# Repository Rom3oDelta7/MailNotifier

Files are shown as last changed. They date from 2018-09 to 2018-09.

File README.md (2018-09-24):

# MailNotifier
Hardware and software solution to be notified when your mail arrives

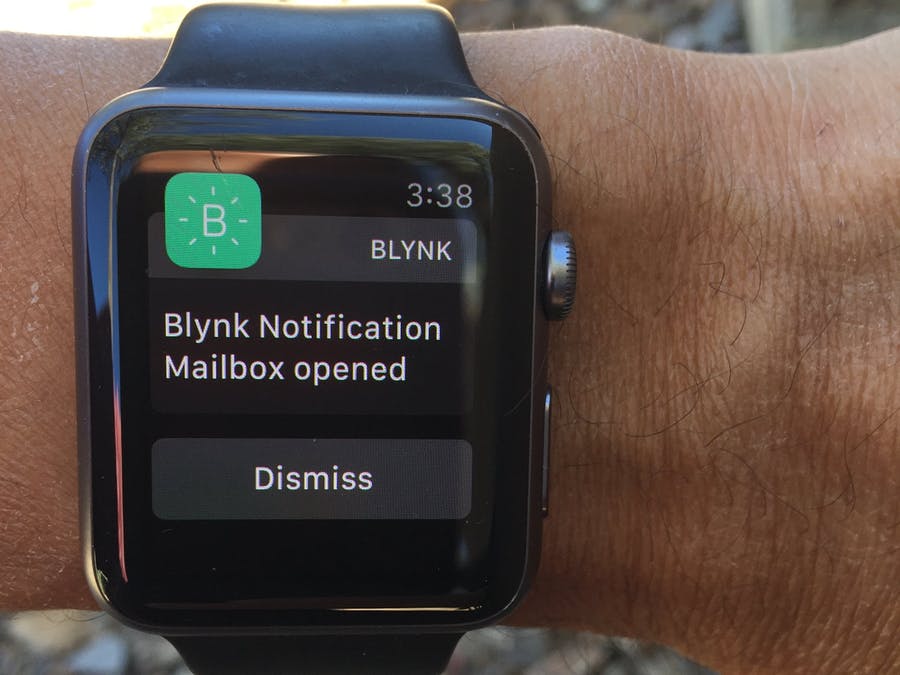
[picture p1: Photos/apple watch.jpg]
Apple Watch notification


This is a simple system that will notify you when your mailbox has been delivered.
You get a notification for the first opening (mail delivered) and the second (mail collected).
These notifications will be sent to your phone using both Blynk and SMS text.
If you have an Apple Watch, the notification will be displayed on the watch as well (see picture above).
The Blynk dashboard provides more information and options, including the date and time the mail was delivered,
what the operating hours are, and status LEDs.

Since the wiring was already in place for my home
I designed this with a wired connection to my mailbox using a standard magnetic reed switch such as that found in
security systems.
Any normally closed switch can be used to sense when the mailbox is open.
If your installation requires a normally open switch instead,
there is a single define in the code that allows you to change the sense.

See more about this projects on [hackster.io].

## Hardware

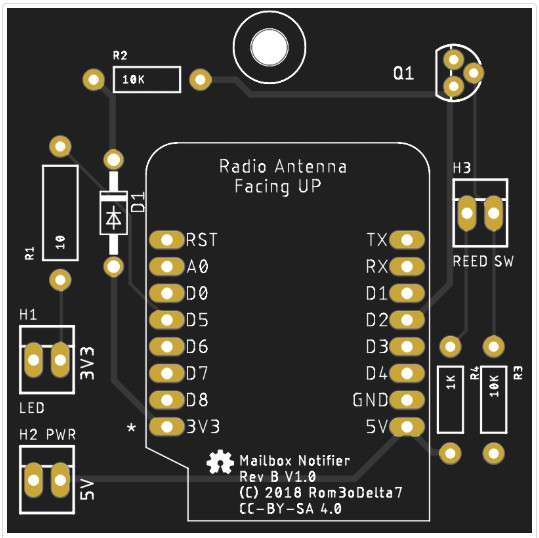
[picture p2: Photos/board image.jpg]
board image


The hardware is quite simple. 
A WeMOS D1 R2 Mini (ESP8266) is used as the controller. There are just 3 connections:
1. the reed switch (which should be normally closed (e.g. magnet is engaged)), and
1. a status LED
1. 5V DV power

The system requires a 5V 1A DC power supply.

Earlier versions of this system suffered from EMI (electromagnetic interference) when lightning stuck nearby
(a common occurrence during the summer monsoons) due in part to a long wire out to the mailbox acting as an antenna.
In Rev B hardware (and Rev 2 software), this issue is handled sensing the switch differently to distinguish an open event from EMI.
Moreover, the lightning-caused high-voltage EMI over time caused the input port to go deaf requiring replacement of the MCU.
Rev B hardware insulates the ESP8266 input port from the external line with a diode and a MOSFET;
these parts have much higher voltage tolerances are easier and cheaper to replace than the ESP8266 MCU module.

PCBs may be ordered from PCBs.io at https://PCBs.io/share/49aNb.

## User Interface

The user interface is shown below:

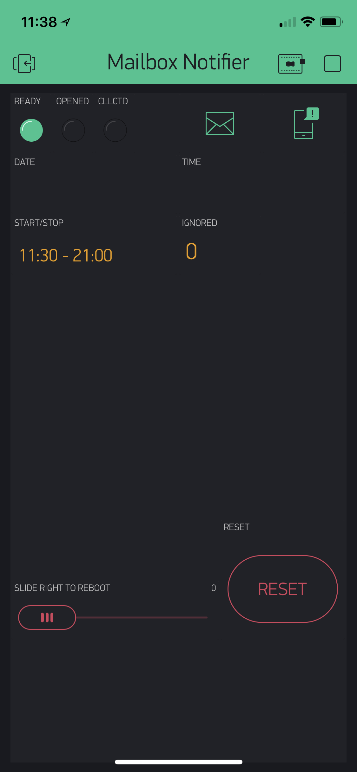
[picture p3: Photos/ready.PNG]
ready state


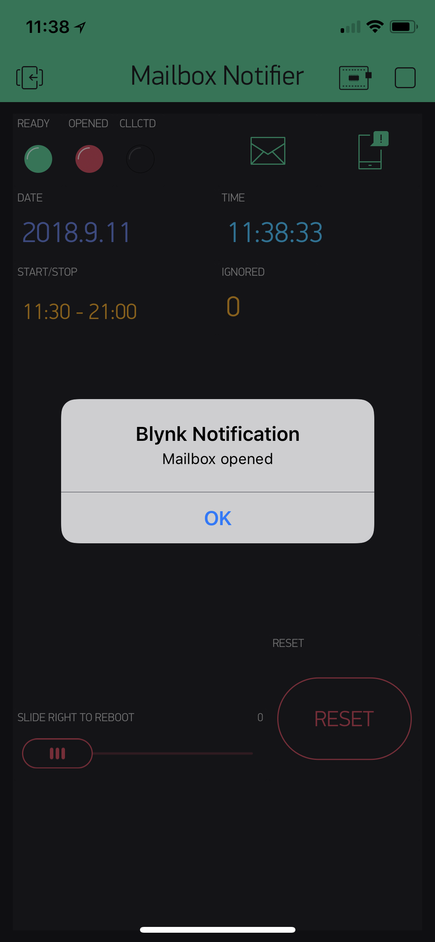
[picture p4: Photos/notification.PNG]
open notification


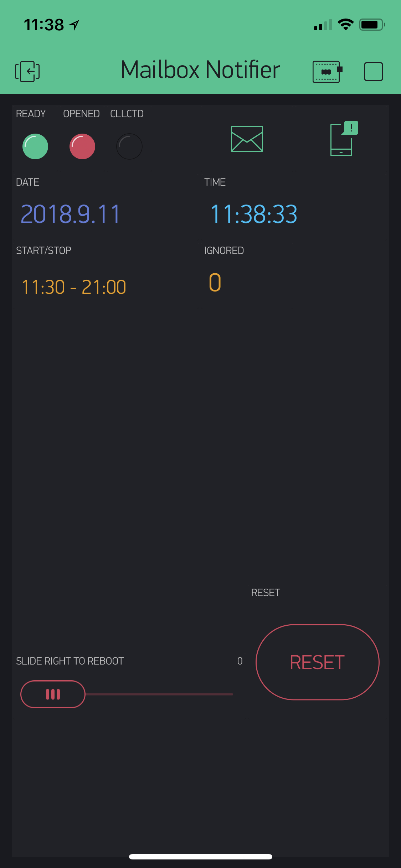
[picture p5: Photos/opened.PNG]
after mail delivered


* The "READY" LED (green) indicates that the mailbox is currently closed.
Note that the ready light will not be on outside operating hours (see below).
* The "OPENED" LED (red) indicates that the mailbox has been opened.
* The "CLLCTD" LED (blue) indicates that the mail has been collected.
This is a heuristic: it is activated if the mailbox is opened _again_ after 10 minutes.
* "DATE" and "TIME" indicate the date (YYYY.MM.DD) and time (24 hr) the mailbox was first opened.
If the mailbox is opened multiple times, the date & time do _not_ change;
you must reset the system (see below) to clear the date & time and reset the indicators.
* The "STOP/START" field is used to set operating hours.
The default is 1100 to 2000 hours.
* "IGNORED" indicates how many times the mailbox was opened outside operating hours.
* The "RESET" button resets the LEDs and the date & time displays.
Note that the system will reset itself automatically at midnight each day.
* The "REBOOT" slider is used to reboot the system.
To reboot, slide the switch all the way to the right.
You have 5 seconds to change your mind and slide it back to the left.
The "READY" LED will extinguish, a message about canceling the reboot will appear in the DATE and TIME displays,
and the system will reboot after a 5 second delay.
Note that this mechanism can also be used to ensure the end-to-end system is running: if the reboot message comes up
this indicates the system is active - just quickly slide the switch back to the left.

Note that all of the built-in delays and timing heuristics can be easily personalized by changing the C++ preprocessor defines in the sketch.

## Firmware

The C++ code uses the [Blynk] service. 
You must first download the Blynk app for your smartphone (iOS or Android) and sign up for the service.
You can then download this app from within Blynk using the QR code in the "Blynk" folder.

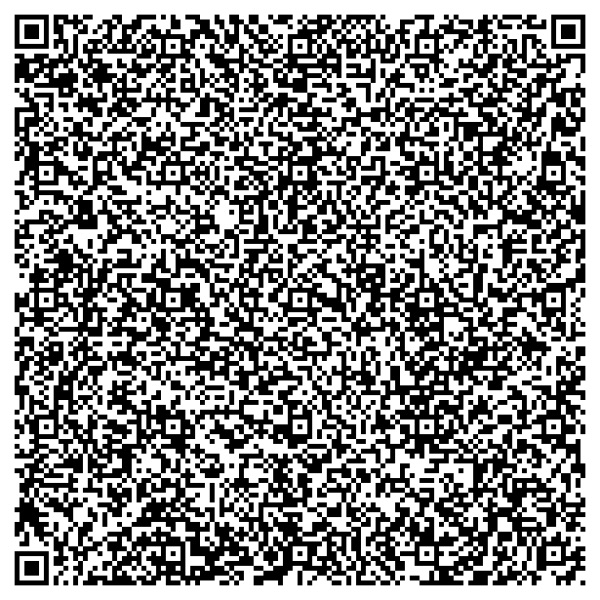
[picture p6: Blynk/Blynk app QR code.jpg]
Blynk mail notifier app QR code


See the [Blynk getting started guide].

The code uses the [Blynk Library], my [NTP (Network Time Protocol) clock library], and Paul Stoffregen's [Time Library].
Be sure to change the "auth", "SSID", and "password" strings
and set the email address string to the [address your carrier uses to send an SMS to your phone] in the file "locals.h". 
In the sketch file, set the parameter to the

```C++
NTP_UTC_Timezone()
```

function to your local timezone. 
See ```WorldTimezones.h``` in the [NTP (Network Time Protocol) clock library] for details and
a list of timezones you can set.

The code may be updated using OTA (Over The Air) updates.
You can still upload the code in the traditional USB approach, but after the firmware has been uploaded for the first time
you can upload subsequent updates over WiFi. 
See the [ESP8266 OTA update documentation] for details.

__Important__: access to the current time is fundamental to the operation of the system.
Therefore, you must have Internet access for the NTP library to work. 

## Enclosure

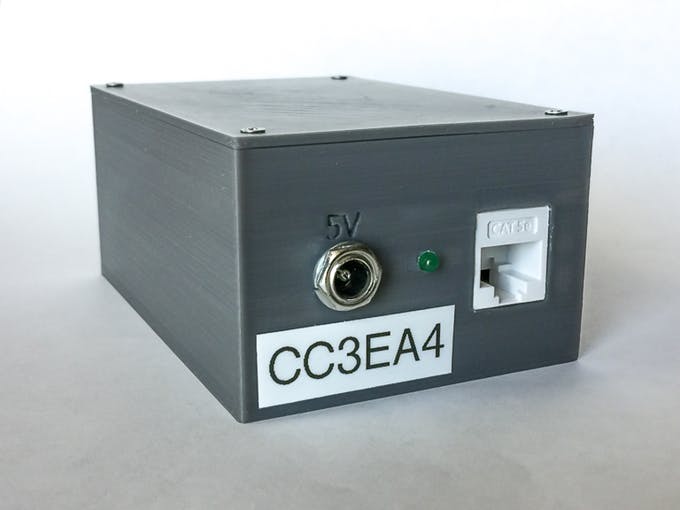
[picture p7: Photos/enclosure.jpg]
enclosure


The STL files to 3D print the enclosure are included in the repo:
one file for the base and one for the lid.
The wiring I piggybacked onto to reach my mailbox happens to come into a patch panel,
so I have an RJ45 jack opening in my enclosure, which is what you see in the picture. 
In your slicing software you should turn on support for the RJ45 opening.
Just about any filament is fine - I used PLA with a layer height of 0.4mm. 
The HEX address you see on the label is the unit address fro OTA updates.

## Implementation

### Assembly

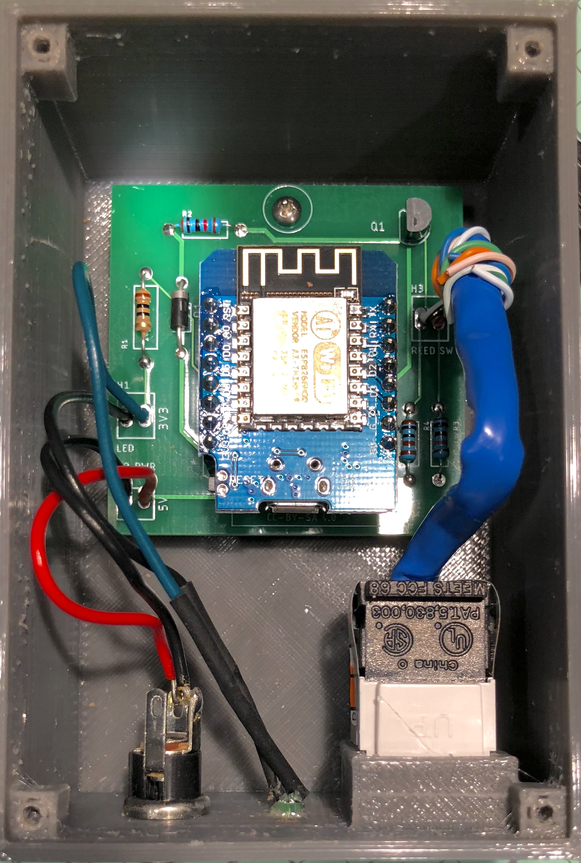
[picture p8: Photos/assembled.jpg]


* 3D print the enclosure base and lid.
* Assemble the discrete components to the PCB.
* Solder the female headers that come with the WeMOS to the PCB.
* If using the RJ45 connector, punch down the switch connection wires into the RJ45 keystone connector,
leaving enough wire to comfortably reach the PCB.
Then insert the RJ45 into the case.
* Solder the connection for the LED and use some 2mm shrink wrap tubing to protect the leads from shorting
(or electrical tape if you don't have this).
* Mount the LED.
The hole is sized for a 3mm LED. If the fit is too loose, then secure the LED to the case with some
UV-curable resin (preferred) or hot melt glue.
If you don't use a green LED, you should recalculate the value of the current limiting resistor
to match the Vf of your LED.
If you don't know what this means, just use a green LED.
* Solder the power wires to the DC power jack and fasten to the case.
* Solder the wires to the PCB: power, switch, and LED, being sure to observe the correct polarity (marked on the PCB).
* Insert the WeMOS into the headers.
__Note:__ You can mount the PCB to the enclosure now, but you will probably find it easier to program it first
(see below).
* Fasten the board to the mounting post in the base of the enclosure.
* Attach the lid using the flat head screws.

### Programming

* Ensure the aforementioned local/personal changes have been implemented in the sketch (.ino) file and "locals.h".
* For the first upload, connect a microUSB plug to the WeMOS.
* In the Arduino IDE, select the "LOLIN(WeMos)D1 R2 & Mini" board.
* Board settings:

|Parameter|Setting|
|---|---|
|CPU Frequency|160 MHz|
|Flash Size|4M(1M SPIFFS)|
|Upload SPeed|921600|
|Port|_your USB serial port_|

* The WeMOS has an automatic system for enabling the flash sequence so no buttons need to be pressed.
* After the code is uploaded, the green LED will illuminate when all of the setup and initialization steps are complete.
* While the serial cable is still connected, open the serial port (115200 baud) and reset the WeMOS.
The HEX address you need to do OTA updates will be printed.
Save this for future use.
At this point, you can launch the Blynk app and run the notifier app dashboard. 
* The USB cable may now be removed.

# Copyright

Copyright 2018 Rob Redford.
This work is licensed under the Creative Commons Attribution-ShareAlike 4.0 International License.
To view a copy of this license, visit [CC-BY-SA].

[hackster.io] https://www.hackster.io/Rom3oDelta7/smartphone-mailbox-notifier-version-2-sept-2018-822a1d
[Blynk]: http://www.blynk.cc/
[Blynk Library]: http://www.blynk.cc/getting-started/
[Blynk getting started guide]: http://www.blynk.cc/getting-started/
[NTP (Network Time Protocol) clock library]: https://github.com/Rom3oDelta7/NTP-RTC
[Time Library]: http://www.pjrc.com/teensy/td_libs_Time.html
[ESP8266 OTA update documentation]: https://arduino-esp8266.readthedocs.io/en/latest/ota_updates/readme.html
[address your carrier uses to send an SMS to your phone]: http://www.digitaltrends.com/mobile/how-to-send-e-mail-to-sms-text/
[CC-BY-SA]: https://creativecommons.org/licenses/by-sa/4.0/

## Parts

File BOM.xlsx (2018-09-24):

Item | Qty | Description | Purchase URL (examplse - available at multiple outlets)
WebMOS D1 mini V2 | 1 | ESP8266-based microcontroller | https://www.banggood.com/WeMos-D1-mini-V2_2_0-WIFI-Internet-Development-Board-Based-ESP8266-4MB-FLASH-ESP-12S-Chip-p-1143874.html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
PCB | 1 | printed circuit board | https://pcbs.io/share/49aNb
Blynk App | 1 | Blynk app & runtime library | www.blynk.cc
1K 1/4W resistor | 1 | 1K PTH resistor | https://octopart.com/search?q=resistor%201K%20ohm%201%2F4%20watt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
10K 1/4W resistor | 2 | 10K PTH resistor | https://octopart.com/search?q=resistor%2010K%20ohm%201%2F4%20watt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
10 ohm 1/4W resistor | 1 | 10 ohm PTH resistor | https://octopart.com/search?q=resistor%2010%20ohm%201%2F4%20watt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
DC jack | 1 | DC power input jack (5.5, 2.1) | https://smile.amazon.com/uxcell-5-5mmx2-1mm-Socket-Mounting-Connector/dp/B01ERPCV1Y
945T magnetic contact | 1 | magnetic reed switch | https://smile.amazon.com/Ademco-945T-WH-Miniature-Surface-Terminals/dp/B000GUQKGC
#2 3/8" flat head screw | 4 | lid screws
#2 1/4" sheet metal screw | 1 | PCB fastener
Green LED | 1 | T-1 (3mm) PTH green LED | https://octopart.com/tlhg4400-vishay-39404959?r=sp&s=afxfcSvbQpS9Ntd6rMgB_Q
MOSFET | 1 | 2N7000 TO-92 pkg | https://octopart.com/search?r=sp&s=afxfcSvbQpS9Ntd6rMgB_Q&q=2N7000&start=0
Diode | 1 | 1N4007 | https://octopart.com/1n4007-t-diodes+inc.-55389582?r=sp&s=AmIHlQKgSlimIGmMg_WMyg
RJ-45 jack | 1 | RJ-45 Cat5e keystone | https://www.monoprice.com/product?p_id=5376
3D printing filament
22 AWG hookup wire

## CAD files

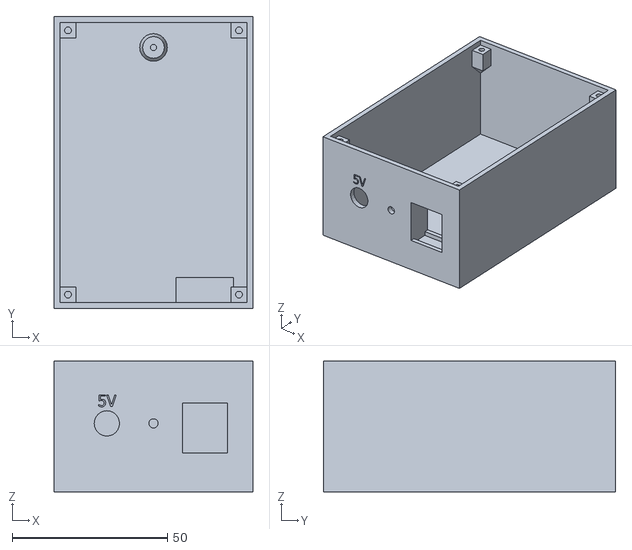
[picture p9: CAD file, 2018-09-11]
Enclosure/Mailbox Notifier Enclosure 0.4.stl
64.0 x 94.0 x 42.0

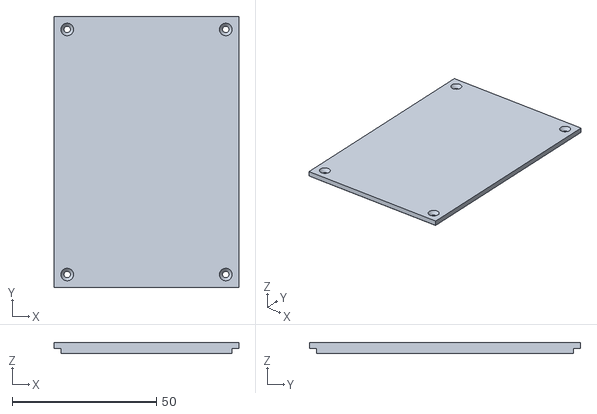
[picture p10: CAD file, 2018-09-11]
Enclosure/Mailbox Notifier Enclosure Lid 0.4.stl
64.0 x 94.0 x 3.80

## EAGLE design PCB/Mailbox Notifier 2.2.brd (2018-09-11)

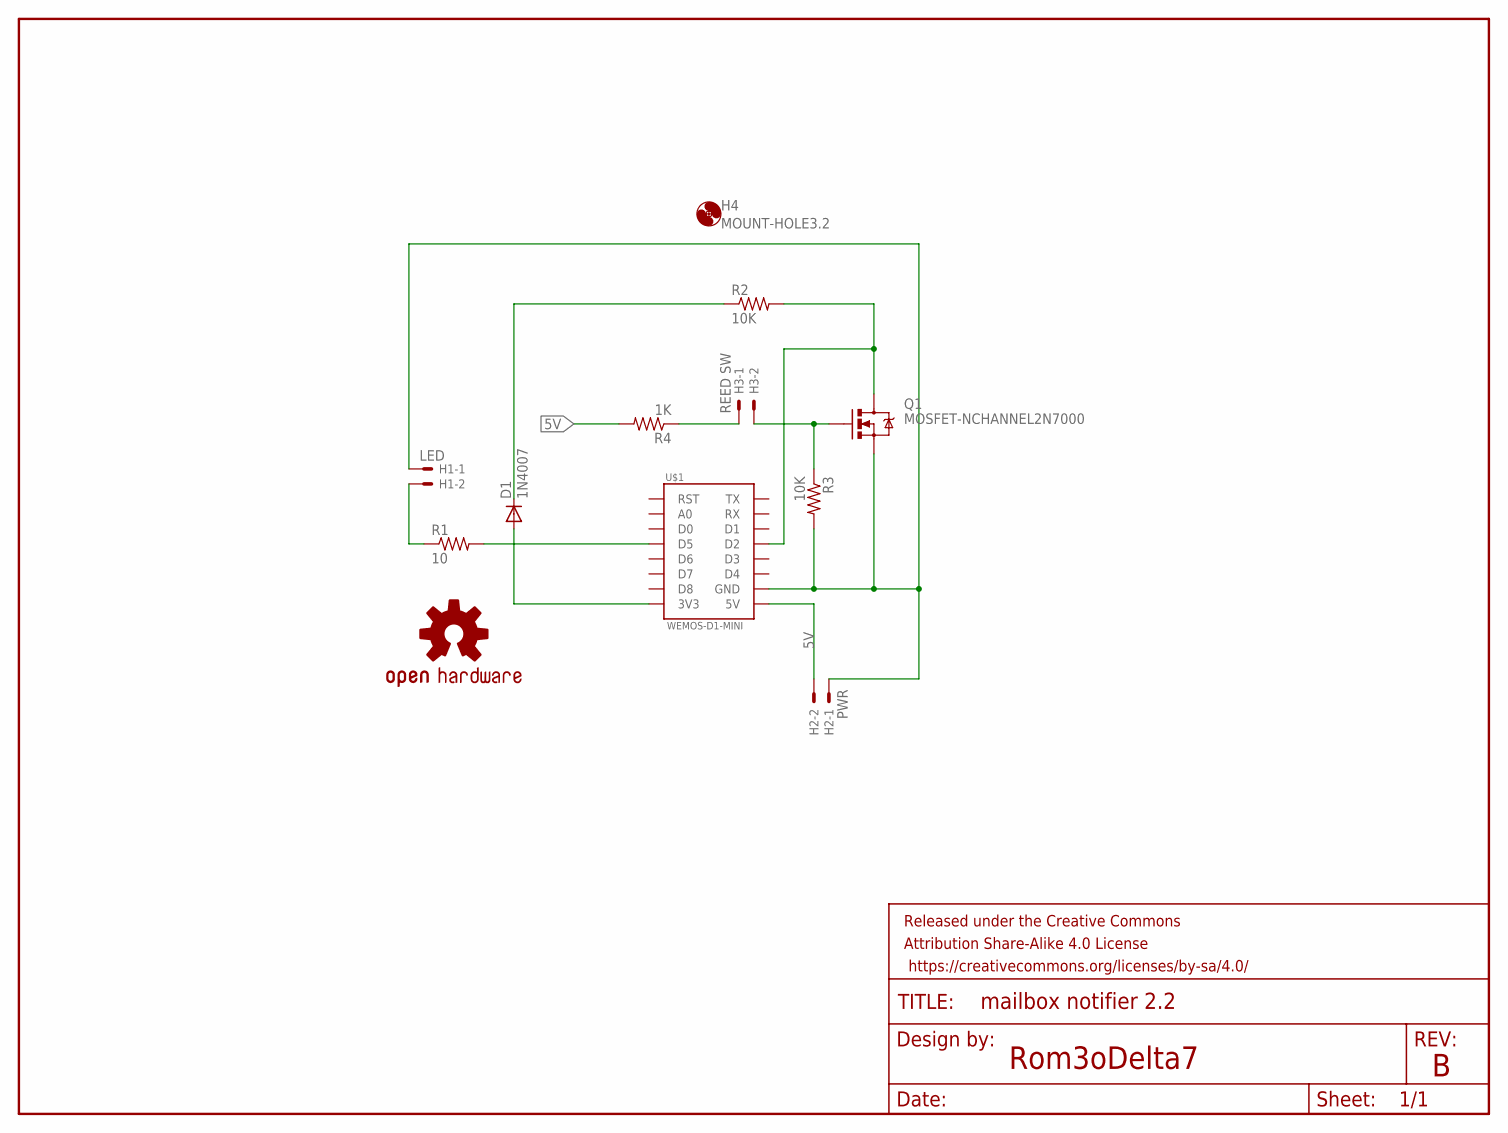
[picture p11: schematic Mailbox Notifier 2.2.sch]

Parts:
D1: 1N4007; DO41-10
FRAME1: FRAME-LETTER; CREATIVE_COMMONS
H1: LED; 22-23-2021
H2: PWR; 22-23-2021
H3: REED SW; 22-23-2021
H4: MOUNT-HOLE3.2; 3,2
LOGO1: OSHW-LOGOMINI; OSHW-LOGO-MINI
Q1: MOSFET-NCHANNEL2N7000; TO-92
R1: 10; AXIAL-0.5
R2, R3: 10K; AXIAL-0.4
R4: 1K; AXIAL-0.4
U$1: WEMOS-D1-MINI

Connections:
5V: H2.2, R4.P$2 (2), U$1.5V
GND: H1.1, H2.1, Q1.1 (S), R3.P$2 (2), U$1.GND
unnamed: D1.A, U$1.3V3
unnamed: H3.2, Q1.2 (G), R3.P$1 (1)
unnamed: R1.P$2 (2), U$1.D5
unnamed: H1.2, R1.P$1 (1)
unnamed: Q1.3 (D), R2.P$2 (2), U$1.D2
unnamed: D1.C, R2.P$1 (1)
unnamed: H3.1, R4.P$1 (1)

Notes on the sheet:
Rom3oDelta7

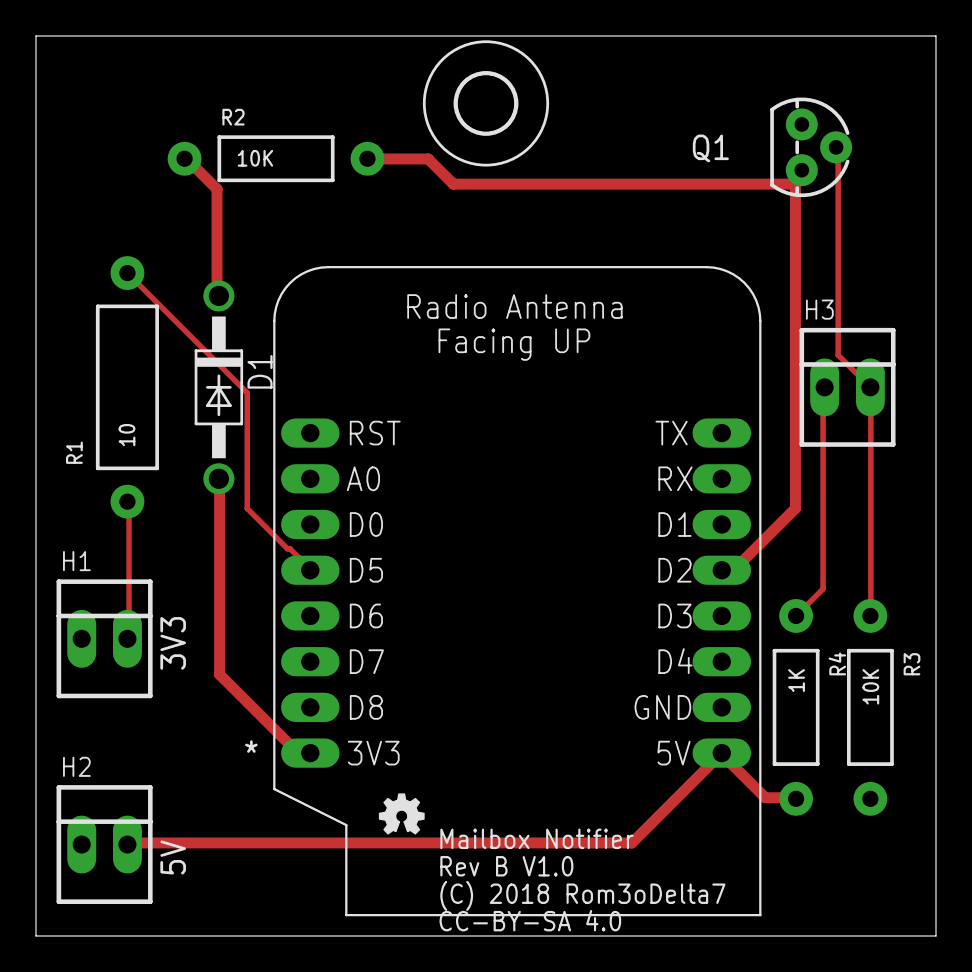
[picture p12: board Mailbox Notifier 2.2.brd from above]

Board: 2 copper layers, 50.0 x 50.0 mm, 13 parts (0 on the bottom side), 9 nets.

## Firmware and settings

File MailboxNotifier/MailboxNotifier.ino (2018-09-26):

/*
	TABS=3
	Mailbox notifier
	Simple Blynk interface for a  magnetic reed switch application
	Supports OTA uploads

	Copyright 2017/2018 Rob Redford
	This work is licensed under the Creative Commons Attribution-ShareAlike 4.0 International License (CC-BY-SA).
	To view a copy of this license, visit https://creativecommons.org/licenses/by-sa/4.0/

*/

//#define DEBUG 3                                    // define as MAX desired debug level, or comment out to disable debug statements

#ifdef DEBUG
   #define BLYNK_PRINT Serial
   #define DEBUG_MSG(L, H, M)	       if ((L) <= DEBUG) {Serial.print("DEBUG> "); Serial.print(H); Serial.print(": "); Serial.println(M);}
#else
   #define DEBUG_MSG(...)            ;
#endif

#include <ESP8266WiFi.h>
#include <BlynkSimpleEsp8266.h>
#include <TimeLib.h>
#include <WiFiUdp.h>
#include <ArduinoOTA.h>
#include <NTPRTC.h>											// https://github.com/Rom3oDelta7/NTP-RTC
#include <WorldTimezones.h>								// https://github.com/Rom3oDelta7/NTP-RTC

// ============================= Local Settings ==================================================

#include "locals.h"

// ============================= Blynk ==================================================

#define DATE_DISPLAY		V1									// Labeled Value, L
#define TIME_DISPLAY		V2									// Labeled Value, L
#define LED_READY			V3									// LED
#define LED_OPEN			V4									// LED
#define RESET_BUTTON		V5									// Button, PUSH
#define START_STOP	   V6									// Time input
#define LED_COLLECTED	V7									// LED
#define REBOOT_SLIDER	V8									// Slider, small
#define IGNORED_EVENTS  V9                         // Value, Small

WidgetLED readyLED(LED_READY);
WidgetLED openedLED(LED_OPEN);
WidgetLED collectedLED(LED_COLLECTED);

// ============================= Hardware & Logic ==========================================

#define NOISE_WINDOW       250                     // dwell time in msec for switch bounce & EMI noise
#define COLLECTION_DELAY	600							// delay in sec after opening before collection window opens
#define CHECK_INTERVAL     500                     // how frequently to check the mailbox (msec)
#define REBOOT_DELAY			5000							// delay in msec for reboot slider

#define DEFAULT_START  		(11 * 3600)	            // 11AM - for operating window
#define DEFAULT_STOP			(20 * 3600)             // 8PM

int      startTimeInSecs = DEFAULT_START;	         // start & stop times from dashboard settings
int      stopTimeInSecs = DEFAULT_STOP;     

int      ignoredEventCount = 0;                    // count of opening events that were ignored

enum CollectionState { C_INACTIVE, C_PENDING, C_ACTIVE };
CollectionState waitingForCollection;				   // flag for 2nd opening, which we assume is to collect the mail

bool     cycleComplete = false;                    // set after mail has been collected to disable further notifications for the day

// use "LOLIN(WeMos)D1 R2 & Mini" to get these defines D2=2, D5=14
#define SWITCH_PIN		D2									// NC switch connected to ground
#define RUNNING_LED		D5									// LED pilot light; 10 ohm resistor, Green LED

#define SENSE_CLOSED    LOW                        // send pin state when mailbox is closed: open:high, closed:low
  

/*
 reset the mailbox switch to normal state
*/
void resetMbox ( void ) {
	openedLED.off();
	collectedLED.off();
	ignoredEventCount = 0;
	Blynk.virtualWrite(TIME_DISPLAY, " ");
	Blynk.virtualWrite(DATE_DISPLAY, " ");
	Blynk.virtualWrite(IGNORED_EVENTS, ignoredEventCount);
	waitingForCollection = C_INACTIVE;
   cycleComplete = false;
}

/*
 Blynk dashboard reset button
*/
BLYNK_WRITE ( RESET_BUTTON ) {
	resetMbox();
}

/*
 set the start and stop time for monitoring the mailbox
 use the Blynk convention of seconds since midnight
 if user does not set this the sketch assumes 24 hour operation
*/
BLYNK_WRITE ( START_STOP ) {
	TimeInputParam startStopTime(param);

	DEBUG_MSG(0, "Called", "START_STOP <<<<<<<<<<<<<<<<<<<<<<<<<<<<<<<<<<<<");
	if ( startStopTime.hasStartTime() ) {
		startTimeInSecs = param[0].asInt();
		if ( startTimeInSecs == -1 ) {
			// no user data entered
			startTimeInSecs = 0;
		}
		DEBUG_MSG(1, "\t\tStart", startTimeInSecs);
	}
	if ( startStopTime.hasStopTime() ) {
		stopTimeInSecs = param[1].asInt();
		if ( stopTimeInSecs == -1 ) {
			stopTimeInSecs = (23*3600) + (59*60) + 59;            // one sec before midnight
		}
		DEBUG_MSG(1, "\t\tStop", stopTimeInSecs);
	}
}


/*
 Reboot the ESP when the slider is all the way to the right (with some margin) but allow the user
 to slide it back to cancel within the specified delay (see above)
 
 Note this can also be used as a test to verify that the ESP is online and responding to commands
*/
BLYNK_WRITE ( REBOOT_SLIDER ) {
	int 		value = param.asInt();
	static 	bool rebootInitiated = false;
	static 	uint32_t rebootRequested = 0;
	
	if ( !rebootInitiated ) {
		if ( value > 90 ) {
			// slider is set to send 0:100
			Blynk.virtualWrite(DATE_DISPLAY, "Slide to 0");
			Blynk.virtualWrite(TIME_DISPLAY, "to cancel");
			rebootInitiated = true;
			rebootRequested = millis();
			readyLED.off();													// turn off to indicate a pending reboot
			Blynk.syncVirtual(REBOOT_SLIDER);                     // send new widget values to dashboard	by forcing call to BLYNK_WRITE()
		}
	} else {
		// process reboot request
		if ( value <= 10 ) {
			// cancel reboot
			rebootInitiated = false;
			Blynk.virtualWrite(DATE_DISPLAY, " ");
			Blynk.virtualWrite(TIME_DISPLAY, " ");
			if ( digitalRead(SWITCH_PIN) == SENSE_CLOSED ) {
				readyLED.on();
			}
		} else if ( (millis() - rebootRequested) < REBOOT_DELAY ) {
			// don't want to call delay(), so just request the value again from the server
			Blynk.syncVirtual(REBOOT_SLIDER);
		} else {
			// still set after delay, so reboot now
			ESP.restart();
			delay(1000);
		}
	}
}

/*
 SETUP
*/
void setup ( void ) {
	Serial.begin(115200);									// always instantiate Serial for OTA messages
   delay(20);
	DEBUG_MSG(0, "Mbox", "*** STARTUP***");

	pinMode(SWITCH_PIN, INPUT);					      // normally closed switch
	pinMode(RUNNING_LED, OUTPUT);
	digitalWrite(RUNNING_LED, LOW);
	
	Blynk.begin(auth, ssid, pass);
	while ( !Blynk.connect() ) {							// wait for connection
		Blynk.run();
	}
	DEBUG_MSG(0, "Mbox", "Blynk CONNECTED");

	if ( digitalRead(SWITCH_PIN) == SENSE_CLOSED ) {
		readyLED.on();
	} else {
		readyLED.off();
	}

	openedLED.off();
	collectedLED.off();
   cycleComplete = false;
   waitingForCollection = C_INACTIVE;
   ignoredEventCount = 0;
	Blynk.virtualWrite(TIME_DISPLAY, " ");
	Blynk.virtualWrite(DATE_DISPLAY, " ");
	Blynk.virtualWrite(IGNORED_EVENTS, ignoredEventCount);
	// the following do not currently work	:-(
	//Blynk.setProperty(START_STOP, "color", "#ED9D00");     // change color to yellow
	//Blynk.virtualWrite(START_STOP, DEFAULT_START, DEFAULT_STOP);
	Blynk.syncVirtual(START_STOP);                           // get current start/stop times

	// initialize NTP source for RTC data
	NTP_UTC_Timezone(UTC_MST);
	NTP_Init();
	
	/*
	 OTA setup
	*/
	// Port defaults to 8266
	ArduinoOTA.setPort(8266);

	// Hostname defaults to esp8266-[ChipID]
	//ArduinoOTA.setHostname("myesp8266");

	// No authentication by default
	//ArduinoOTA.setPassword((const char *)"@kermit87");

	ArduinoOTA.onStart([]() {
		Serial.println("Start");
	});
	ArduinoOTA.onEnd([]() {
		Serial.println("\nEnd. Restarting ...");
		ESP.restart();
		delay(1000);
	});
	ArduinoOTA.onProgress([](unsigned int progress, unsigned int total) {
		Serial.printf("Progress: %u%%\r", (progress / (total / 100)));
	});
	ArduinoOTA.onError([](ota_error_t error) {
		Serial.printf("Error[%u]: ", error);
		switch ( error ) {
		case OTA_AUTH_ERROR:
			Serial.println("Auth Failed");
			break;
			
		case OTA_BEGIN_ERROR:
			Serial.println("Begin Failed");
			break;
			
		case OTA_CONNECT_ERROR:
			Serial.println("Connect Failed");
			break;
			
		case OTA_RECEIVE_ERROR:
			Serial.println("Receive Failed");
			break;
			
		case OTA_END_ERROR:
			Serial.println("End Failed");
			break;
			
		default:
			Serial.println("Unknown error");
			break;
		}
	});
	ArduinoOTA.begin();
	Serial.println("OTA Ready:");
	Serial.print("\tIP address: ");
	Serial.println(WiFi.localIP());
	Serial.print("\tChip ID: ");
	Serial.println(ESP.getChipId(), HEX);
	
	digitalWrite(RUNNING_LED, HIGH);
}

/*
 update Blynk dashboard with the time the mailbox was opened
*/
void displayOpenedTime ( void ) {
	char    currentTime[9];
	time_t  timeNow = now();
	
	// use a constant time value to avoid corner cases where, for example, the hour changes between function calls
	sprintf(currentTime, "%02d:%02d:%02d", hour(timeNow), minute(timeNow), second(timeNow));
	String currentDate = String(year(timeNow)) + "." + month(timeNow) + "." + day(timeNow);
	DEBUG_MSG(2, "current time", currentTime);
	DEBUG_MSG(2, "current date", currentDate);

	Blynk.virtualWrite(TIME_DISPLAY, currentTime);
	Blynk.virtualWrite(DATE_DISPLAY, currentDate);
}

/*
 Check switch pin to determine if the mailbox is open.
 
 When the switch is closed, the MOSFET gate will be high and the MOSFET will be "on", connecting the 
 drain and source and grounding the connection. In this state the 8266 pin will read "low".
 When the switch is open, the gate will be pulled low, and the MOSFT will be off. The 8266 pin will then read the voltage differential 
 on the drain pin and  read as "high".
 
 But if this is an EMI event instead, then after some initial noise, the line will still be low.
 Therefore, if the pin is high, wait for the debounce/EMI noise to settle, then read the line again -
 this should be the actual state.
 
 Note: the EMI issue only comes into play if we happen to be reading the pin while the EMI is occurring.
 Since we're reading the pin quite frequently, this may still happen. Adjust the delay if the time interval is insufficient,
 but don't wait so long that the mailbox may have been closed after delivery (and thus missing the event).
 */
bool mailboxIsOpen ( void ) {
   if ( digitalRead(SWITCH_PIN) == SENSE_CLOSED ) {
      return false;
   } else {
      // if low again after delay, then initial read was a false positive
      delay(NOISE_WINDOW);
      return digitalRead(SWITCH_PIN);
   }
}

/*
 LOOP
*/
void loop ( void ) {
	static int    today = day();
	static time_t timeOpened = 0;
   static bool    ignoredEventCounted = false;
#ifdef DEBUG
	static bool   displayed = false;
#endif
	
	if ( today != day() ) {
		// automatically reset state every day
		today = day();
		resetMbox();
	}
	
	// check for operating hours. Default (params not set by user) is 24hr operation
	int currentTimeinSecs = ((3600 * hour()) + (60 * minute()) + second());
#if DEBUG > 3
	if ( (second() % 5) == 0 ) {
		if ( !displayed ) {
			displayed = true;
			DEBUG_MSG(3, "current seconds since midnight", currentTimeinSecs);
			DEBUG_MSG(3, "start", startTimeInSecs);
			DEBUG_MSG(3, "stop", stopTimeInSecs);
		}
	} else {
		displayed = false;
	}
#endif
   
   delay(CHECK_INTERVAL);                   // no need to constantly check - also helps with EMI
   if ( !cycleComplete ) {
      bool mailboxOpen = mailboxIsOpen();
      DEBUG_MSG(2, "Loop:Status:", mailboxOpen);
      if ( (currentTimeinSecs >= startTimeInSecs) && (currentTimeinSecs < stopTimeInSecs) ) {
         // inside the operating window
         if ( mailboxOpen ) {
            // mailbox initial open
            DEBUG_MSG(2, "OPEN: Collection state:", waitingForCollection);
            readyLED.off();

            switch ( waitingForCollection ) {
               case C_INACTIVE:
                  // first time mailbox has been opened
                  DEBUG_MSG(2, "Loop:\t", "mailbox opened");
                  Blynk.email(SMS_EMAIL, "Mbox Notifier", "Mailbox opened");
                  Blynk.notify("Mailbox opened");
                  displayOpenedTime();
                  timeOpened = now();
                  openedLED.on();
                  waitingForCollection = C_PENDING;
                  ignoredEventCounted = false;
                  break;
                  
               case C_ACTIVE:
                  if ( (now() - timeOpened) >= COLLECTION_DELAY ) {
                     /*
                      second opening - assume this is to collect the mail
                      ignore it if not enough time has passed yet 
                     */
                     collectedLED.on();
                     Blynk.email(SMS_EMAIL, "Mbox Notifier", "Mail collected");
                     Blynk.notify("Mail collected");
                     DEBUG_MSG(2, "Loop:\t", "mail collected");
                     waitingForCollection = C_INACTIVE;
                     cycleComplete = true;
                  } else if ( !ignoredEventCounted ) {
                     // count these as a single ignored event
                     ++ignoredEventCount;
                     ignoredEventCounted = true;
                     Blynk.virtualWrite(IGNORED_EVENTS, ignoredEventCount);
                  }
                  break;
                  
               default:
                  break;
            }
         } else { 
            //closed
            if ( waitingForCollection == C_PENDING ) {
               // ensure mailbox has been closed first before checking for collection
               waitingForCollection = C_ACTIVE;
               DEBUG_MSG(3, "Loop:", "mailbox closed before collection");
            }
            ignoredEventCounted = false;
            readyLED.on();
         }
      } else {
         // ignore events outside working time (count events until cycle is complete, then stop counting)
         readyLED.off();                    // turn off when outside working window
         static bool alreadyOpen = false;
         
         // only count an event if the mailbox has been closed since we last saw the open state
         if ( !alreadyOpen && mailboxOpen ) {
            // closed -> open
            ++ignoredEventCount;
            alreadyOpen = true;
            Blynk.virtualWrite(IGNORED_EVENTS, ignoredEventCount);
         } else if ( alreadyOpen && !mailboxOpen ) {
            // open -> closed
            alreadyOpen = false;
         }
      }
   }
   
	// housekeeping
	Blynk.run();
	yield();
	ArduinoOTA.handle();
}

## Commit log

2018-09-11 Initial checkin RevB/2
    [Mailbox Notifier 2.1.GBL, Mailbox Notifier 2.1.GBO, Mailbox Notifier 2.1.GBS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]
2018-09-11 Final Eagle files
    [Mailbox Notifier 2.2.GBL, Mailbox Notifier 2.2.GBO, Mailbox Notifier 2.2.GBS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]
2018-09-11 bill of materia;s
    [BOM.xlsx]
2018-09-20 Fix incorrect pin definitionsleft over from Rev A hardware
    [MailboxNotifier.ino]
2018-09-22 update build instructions to current board name (LOLIN(WeMos)D1 R2 & Mini)) update comments in sketch
2018-09-22 add photo of assembled unit
2018-09-22 add assembled image photo link to README
2018-09-22 note that Blynk watch app is not currently available
2018-09-24 Update README, add hackster.io project link, and add missing diode to BOM
    [BOM.xlsx]

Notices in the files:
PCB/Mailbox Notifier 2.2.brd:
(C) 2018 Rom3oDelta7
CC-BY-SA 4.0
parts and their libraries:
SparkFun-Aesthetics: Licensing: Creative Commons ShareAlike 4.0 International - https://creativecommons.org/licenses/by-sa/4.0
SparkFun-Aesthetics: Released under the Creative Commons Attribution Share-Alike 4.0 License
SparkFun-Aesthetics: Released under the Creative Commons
